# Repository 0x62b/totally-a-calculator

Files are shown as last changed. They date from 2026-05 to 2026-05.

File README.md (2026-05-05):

# totally a calculator
This is a RPi Pico powered...calculator...with an extensive library of..."extra apps" one could say.
The sole purpose of this project is to satisfy the ask of one of my classmates :sob:

[Onshape link](https://cad.onshape.com/documents/416f156d5c7fec03dfea0d3a/w/a37f3b67ee07a3cc1823a5f4/e/b4b6719643a130719caaa4b0)
Note: the display appears to be unaligned due to the fact that i used a different display to the model in the render. However, I designed the case around the display being used, so it should be fine.

## Repo structure
`firmware/` for the (not completed) firmware
`cad/` for CAD design files
`images/` for images in this readme
`pcb/` for KiCad design files and `pcb/gerbers` for production files
`bom.csv` for BOM

## Cost
The BOM prices are approximate due to conversion rates and Aliexpress fluctuations
BOM: 27.03 USD
PCB: 4 USD + 1.5 USD shipping (approx)
Total: 32.53 USD

## Assembly
Prerequisites: print the case parts and solder the PCB
1. Put PCB into bottom case
2. Screw top case onto bottom case
3. Glue or otherwise stick each individual keycap onto the buttons
4. Attach the OLED
5. Screw it in
6. Flash the MicroPython firmware for the Pico
7. Upload the python file in `firmware/`
8. yay

## Images

### Schematic
Beautifully clean and organised (/s) schematic
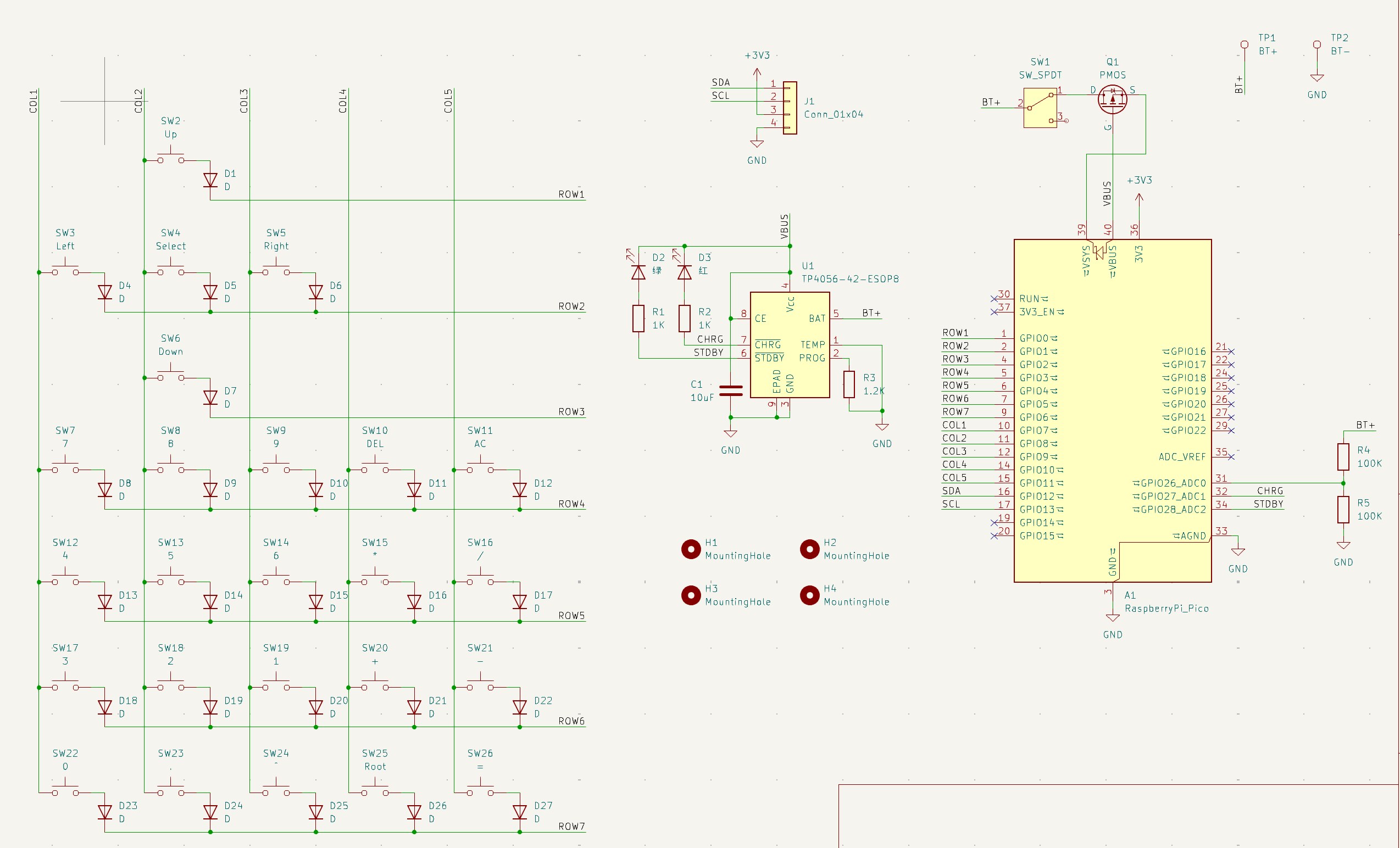
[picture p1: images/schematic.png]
schematic


### PCB render
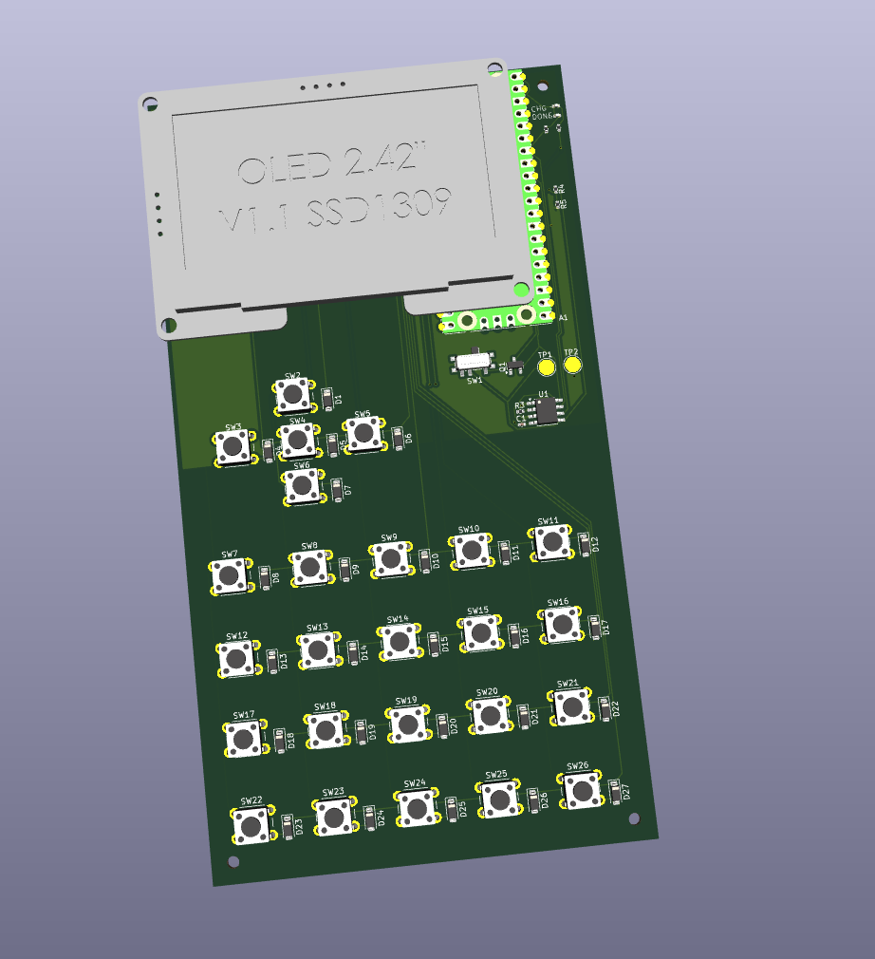
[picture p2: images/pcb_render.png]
pcb render


### Full render
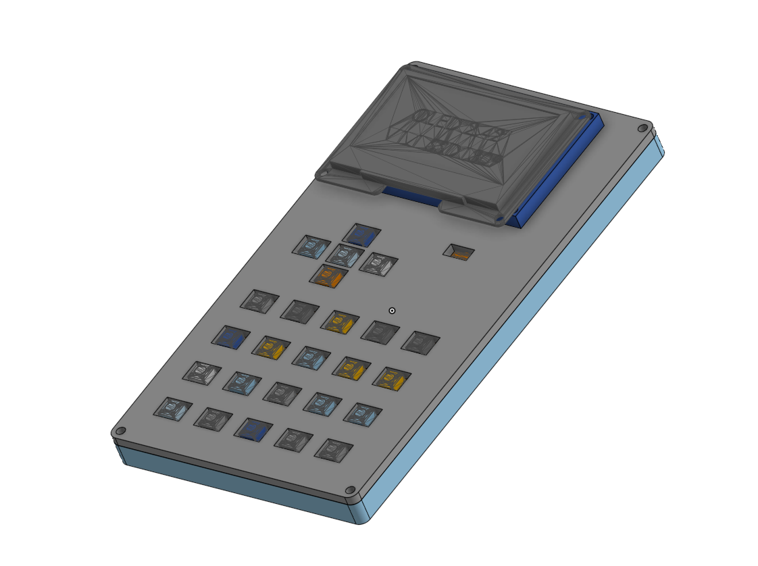
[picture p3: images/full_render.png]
full render


### Zine
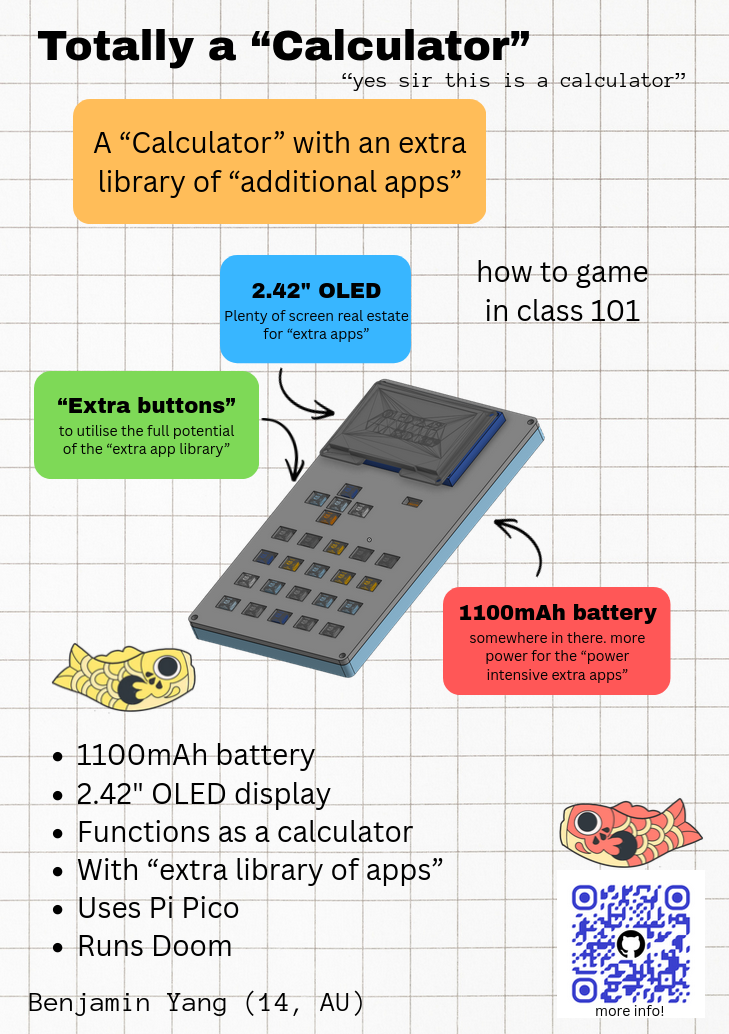
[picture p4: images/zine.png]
zine


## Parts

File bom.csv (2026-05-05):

Item | Unit Price(AUD) | Quantity | Extended Price(AUD) | Extended Price(USD) | Notes | Link
OLED | 18.49 | 1 | 18.49 | 13.22 | N/A | https://www.aliexpress.com/item/1005009013981317.html
Buttons | 3.79 | 1 | 3.79 | 2.71 | 50 in pack | https://www.aliexpress.com/item/1005001813038293.html
Green LED | 0 | 1 | 0 | 0 | owned | N/A
Red LED | 0 | 1 | 0 | 0 | owned | N/A
1K resistor | 0 | 2 | 0 | 0 | owned | N/A
100K resistor | 0 | 2 | 0 | 0 | owned | N/A
1.2K resistor | 2.48 | 1 | 2.48 | 1.77 | 300 per pack | https://www.aliexpress.com/item/1005011779163101.html
TP4056 | 4.01 | 1 | 4.01 | 2.87 | 10 per pack - TC4056A | https://www.aliexpress.com/item/1005010183126676.html
1100mAh battery | 0 | 1 | 0 | 0 | owned | https://core-electronics.com.au/polymer-lithium-ion-battery-1000mah-38458.html
SPDT switch | 2.89 | 1 | 2.89 | 2.07 | 50 per pack | https://www.aliexpress.com/item/4000685483225.html
DMG2305UX P-MOSFET | 6.14 | 1 | 6.14 | 4.39 | 30 per pack | https://www.aliexpress.com/item/1005007188534627.html
Pi Pico | 0 | 1 | 0 | 0 | owned | https://core-electronics.com.au/raspberry-pi-pico-2-w-wireless.html
M3 screws | 0 | 8 | 0 | 0 | owned | N/A

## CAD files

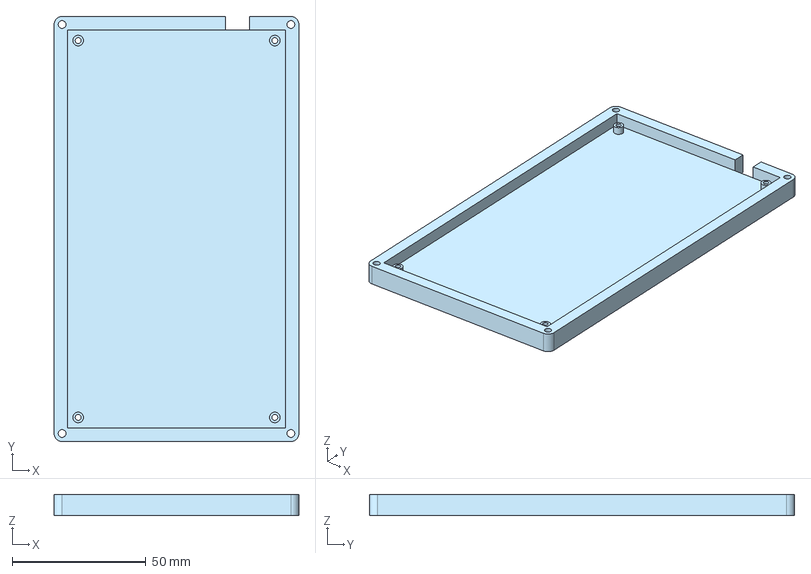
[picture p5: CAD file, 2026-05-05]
cad/bottom case.step
91.6 x 159.0 x 8.00 mm

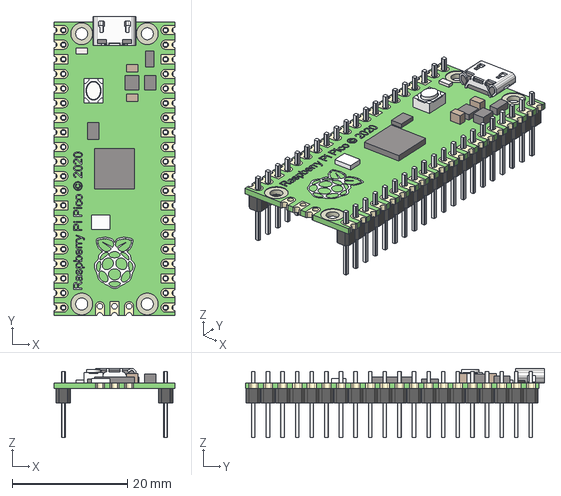
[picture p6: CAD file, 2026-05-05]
pcb/raspberry pi pico with contacts.step
21.0 x 52.0 x 12.0 mm
ножка x 20
ножка v3(Mirror) x 20

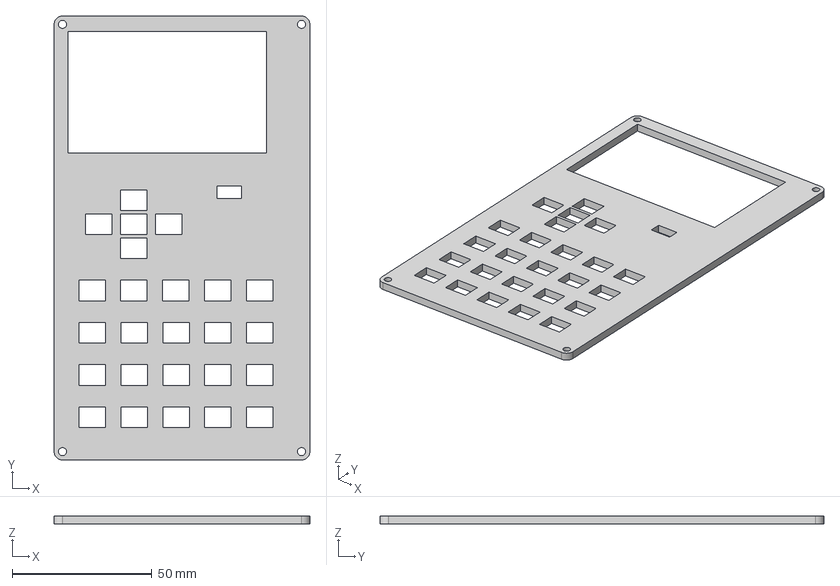
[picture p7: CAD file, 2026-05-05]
cad/top case.step
91.6 x 159.0 x 3.00 mm

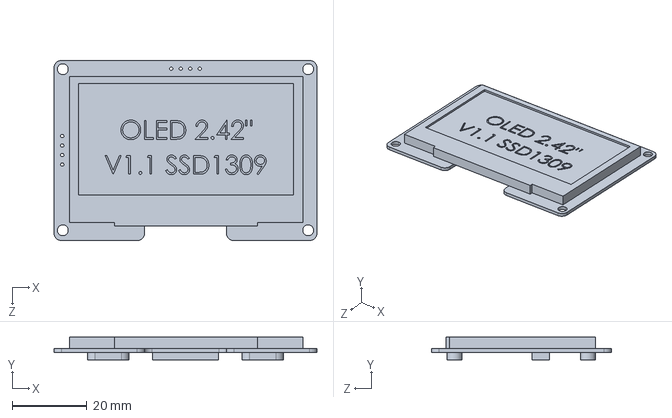
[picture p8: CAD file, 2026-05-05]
pcb/OLED 2.42 V1.1 SSD1309.STEP
70.2 x 6.10 x 48.1 mm

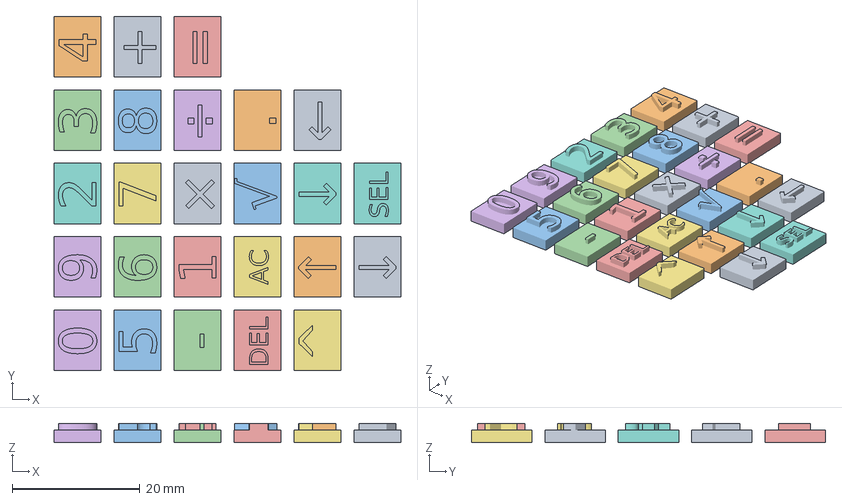
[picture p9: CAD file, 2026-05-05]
cad/keys.3mf
54.4 x 55.5 x 2.98 mm

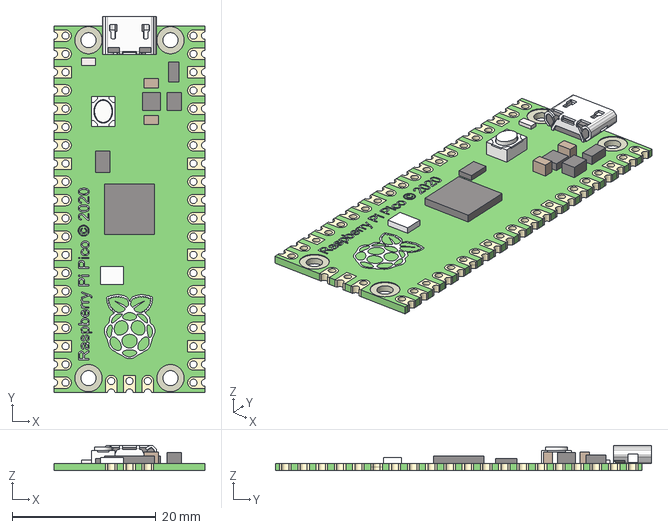
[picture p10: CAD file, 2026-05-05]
pcb/raspberry pi pico.step
21.0 x 52.3 x 3.50 mm

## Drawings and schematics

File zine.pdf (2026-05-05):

## Totally a “Calculator”

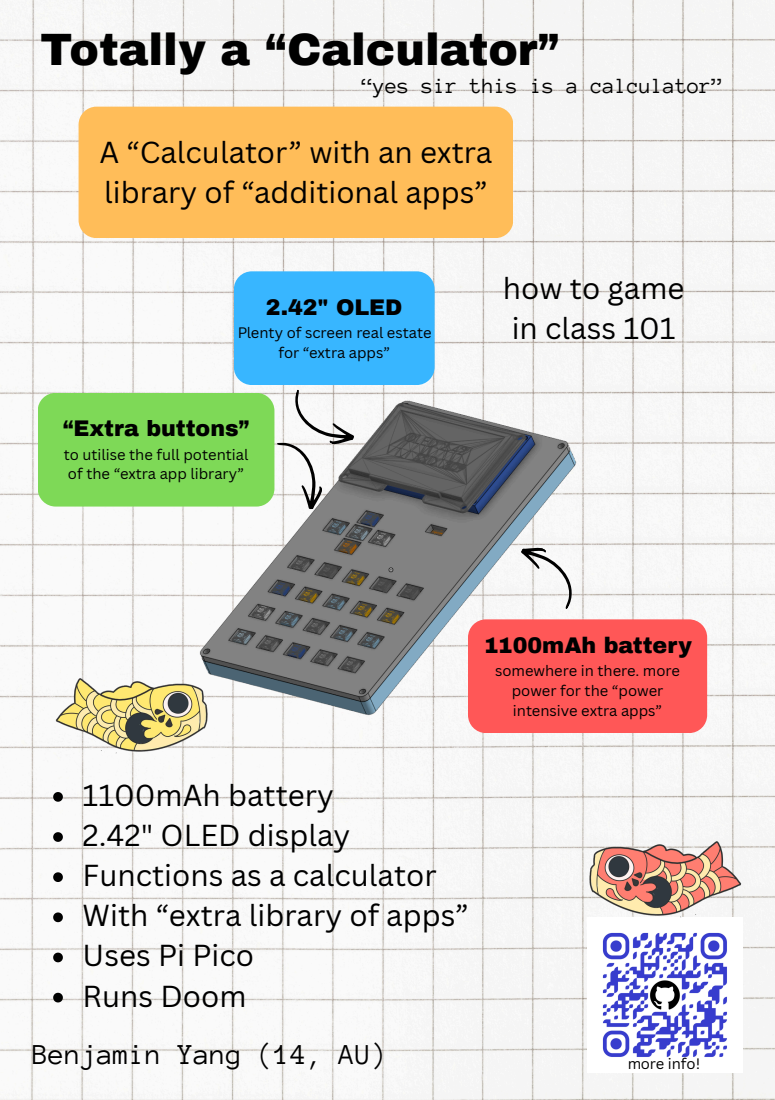
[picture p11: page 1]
more info!

“yes sir this is a calculator”

A “Calculator” with an extra
library of “additional apps”

how to game
in class 101

2.42" OLED
Plenty of screen real estate
for “extra apps”

“Extra buttons”
to utilise the full potential
of the “extra app library”

1100mAh battery
somewhere in there. more
power for the “power
intensive extra apps”

2.42" OLED display
Functions as a calculator
With “extra library of apps”
Uses Pi Pico
Runs Doom

Benjamin Yang (14, AU)

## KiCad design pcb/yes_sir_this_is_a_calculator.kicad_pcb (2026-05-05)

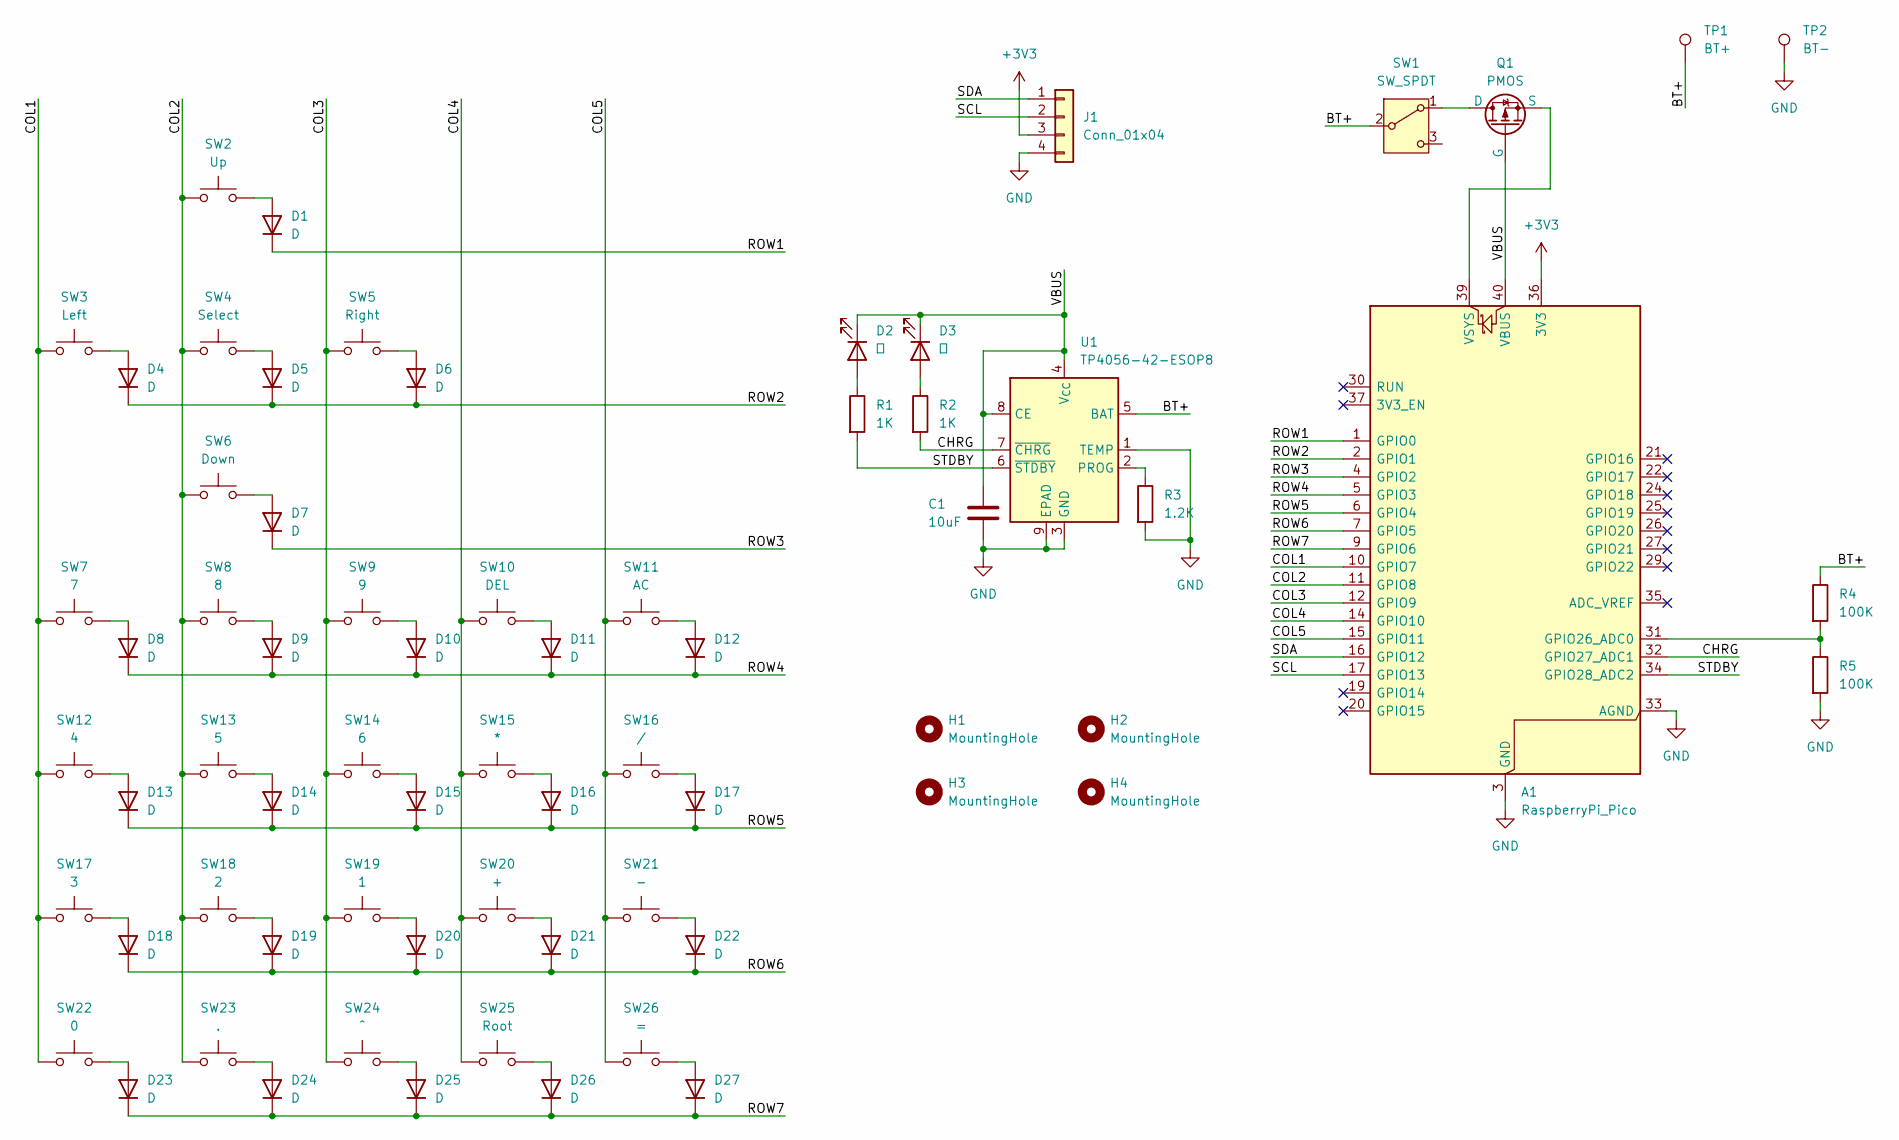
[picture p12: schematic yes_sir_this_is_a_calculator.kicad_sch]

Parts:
A1: RaspberryPi_Pico; RaspberryPi_Pico_Common_Unspecified
C1: 10uF; C_0402_1005Metric
D1, D4, D5, D6, D7, D8, D9, D10, D11, D12, D13, D14, D15, D16, D17, D18, D19, D20, D21, D22, D23, D24, D25, D26, D27: D; D_SOD-123
D2: 绿; LED_0402_1005Metric
D3: 红; LED_0402_1005Metric
H1, H2, H3, H4: MountingHole; MountingHole_2.2mm_M2
J1: Conn_01x04; PinSocket_1x04_P2.54mm_Vertical
Q1: PMOS; SOT-23
R1, R2: 1K; R_0402_1005Metric
R3: 1.2K; R_0402_1005Metric
R4, R5: 100K; R_0402_1005Metric
SW1: SW_SPDT; SW_SPDT_PCM12
SW2: Up; SW_PUSH_6mm
SW3: Left; SW_PUSH_6mm
SW4: Select; SW_PUSH_6mm
SW5: Right; SW_PUSH_6mm
SW6: Down; SW_PUSH_6mm
SW7: 7; SW_PUSH_6mm
SW8: 8; SW_PUSH_6mm
SW9: 9; SW_PUSH_6mm
SW10: DEL; SW_PUSH_6mm
SW11: AC; SW_PUSH_6mm
SW12: 4; SW_PUSH_6mm
SW13: 5; SW_PUSH_6mm
SW14: 6; SW_PUSH_6mm
SW15: *; SW_PUSH_6mm
SW16: /; SW_PUSH_6mm
SW17: 3; SW_PUSH_6mm
SW18: 2; SW_PUSH_6mm
SW19: 1; SW_PUSH_6mm
SW20: +; SW_PUSH_6mm
SW21: -; SW_PUSH_6mm
SW22: 0; SW_PUSH_6mm
SW23: .; SW_PUSH_6mm
SW24: ^; SW_PUSH_6mm
SW25: Root; SW_PUSH_6mm
SW26: =; SW_PUSH_6mm
TP1: BT+; TestPoint_Pad_D3.0mm
TP2: BT-; TestPoint_Pad_D3.0mm
U1: TP4056-42-ESOP8; SOIC-8-1EP_3.9x4.9mm_P1.27mm_EP2.41x3.3mm_ThermalVias

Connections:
+3V3: A1.36 (3V3), J1.3
/BT+: R4.1, SW1.2 (B), TP1.1, U1.5 (BAT)
/CHRG: A1.32 (GPIO27_ADC1), R2.2, U1.7 (~CHRG)
/COL1: A1.10 (GPIO7), SW3.1, SW7.1, SW12.1, SW17.1, SW22.1
/COL2: A1.11 (GPIO8), SW2.1, SW4.1, SW6.1, SW8.1, SW13.1, SW18.1, SW23.1
/COL3: A1.12 (GPIO9), SW5.1, SW9.1, SW14.1, SW19.1, SW24.1
/COL4: A1.14 (GPIO10), SW10.1, SW15.1, SW20.1, SW25.1
/COL5: A1.15 (GPIO11), SW11.1, SW16.1, SW21.1, SW26.1
/ROW1: A1.1 (GPIO0), D1.1 (K)
/ROW2: A1.2 (GPIO1), D4.1 (K), D5.1 (K), D6.1 (K)
/ROW3: A1.4 (GPIO2), D7.1 (K)
/ROW4: A1.5 (GPIO3), D8.1 (K), D9.1 (K), D10.1 (K), D11.1 (K), D12.1 (K)
/ROW5: A1.6 (GPIO4), D13.1 (K), D14.1 (K), D15.1 (K), D16.1 (K), D17.1 (K)
/ROW6: A1.7 (GPIO5), D18.1 (K), D19.1 (K), D20.1 (K), D21.1 (K), D22.1 (K)
/ROW7: A1.9 (GPIO6), D23.1 (K), D24.1 (K), D25.1 (K), D26.1 (K), D27.1 (K)
/SCL: A1.17 (GPIO13), J1.2
/SDA: A1.16 (GPIO12), J1.1
/STDBY: A1.34 (GPIO28_ADC2), R1.2, U1.6 (~STDBY)
/VBUS: A1.40 (VBUS), C1.2, D2.1 (K), D3.1 (K), Q1.2 (G), U1.4 (V_{CC}), U1.8 (CE)
GND: A1.3 (GND), A1.8 (GND), A1.13 (GND), A1.18 (GND), A1.23 (GND), A1.28 (GND), A1.33 (AGND), A1.38 (GND), C1.1, J1.4, R3.2, R5.2, TP2.1, U1.1 (TEMP), U1.3 (GND), U1.9 (EPAD)
unnamed: A1.31 (GPIO26_ADC0), R4.2, R5.1
unnamed: A1.39 (VSYS), Q1.3 (S)
unnamed: D1.2 (A), SW2.2
unnamed: D2.2 (A), R1.1
unnamed: D3.2 (A), R2.1
unnamed: D4.2 (A), SW3.2
unnamed: D5.2 (A), SW4.2
unnamed: D6.2 (A), SW5.2
unnamed: D7.2 (A), SW6.2
unnamed: D8.2 (A), SW7.2
unnamed: D9.2 (A), SW8.2
unnamed: D10.2 (A), SW9.2
unnamed: D11.2 (A), SW10.2
unnamed: D12.2 (A), SW11.2
unnamed: D13.2 (A), SW12.2
unnamed: D14.2 (A), SW13.2
unnamed: D15.2 (A), SW14.2
unnamed: D16.2 (A), SW15.2
unnamed: D17.2 (A), SW16.2
unnamed: D18.2 (A), SW17.2
unnamed: D19.2 (A), SW18.2
unnamed: D20.2 (A), SW19.2
unnamed: D21.2 (A), SW20.2
unnamed: D22.2 (A), SW21.2
unnamed: D23.2 (A), SW22.2
unnamed: D24.2 (A), SW23.2
unnamed: D25.2 (A), SW24.2
unnamed: D26.2 (A), SW25.2
unnamed: D27.2 (A), SW26.2
unnamed: Q1.1 (D), SW1.1 (A)
unnamed: R3.1, U1.2 (PROG)

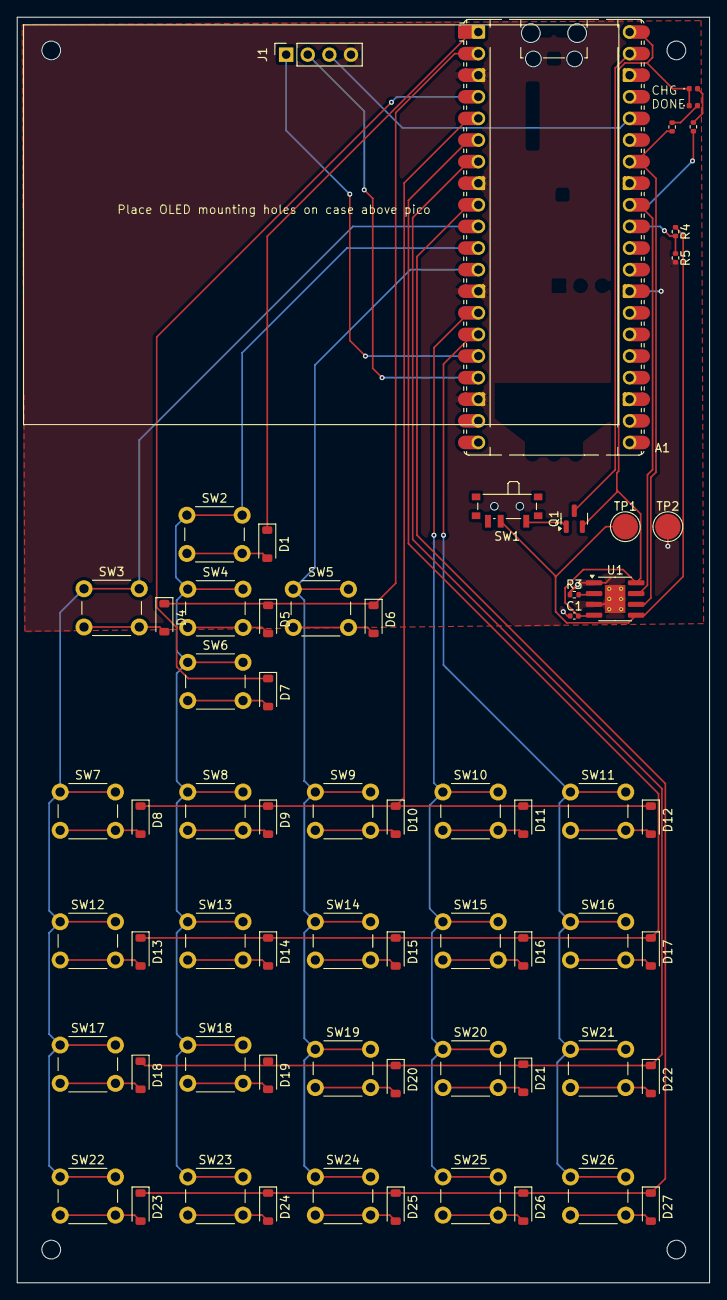
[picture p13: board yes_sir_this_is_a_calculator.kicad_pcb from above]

Board: 2 copper layers, 81.4 x 148.8 mm, 69 parts (0 on the bottom side), 51 nets.

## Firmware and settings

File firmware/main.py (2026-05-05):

from machine import Pin
import time

ROW_PINS = [0, 1, 2, 3, 4, 5, 6]
COL_PINS = [7, 8, 9, 10, 11]
SDA_PIN = 12
SCL_PIN = 13

rows = [Pin(p, Pin.OUT) for p in ROW_PINS]
cols = [Pin(p, Pin.IN, Pin.PULL_UP) for p in COL_PINS]

for r in rows:
  r.value(1)

keymap = [
  ["",     "Up",   "",      "",    ""],
  ["Left", "Sel",  "Right", "",    ""],
  ["",     "Down", "",      "",    ""],
  ["7",    "8",    "9",     "DEL", "AC"],
  ["4",    "5",    "6",     "*",   "/"],
  ["3",    "2",    "1",     "+",   "-"],
  ["0",    ".",    "~",     "SQT", "="]
]

def scan():
  for r in rows:
    r.value(0)
    
    for c in cols:
      if c.value() == 0:
        r.value(1)
        return keymap[rows.index(r)][cols.index(c)]
        
    r.value(1)

while True:
  key = scan()
  if key:
    print(key)
  
  time.sleep(0.05)

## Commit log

2026-05-05 CAD files
    [bottom case.step, top case.step]
2026-05-05 add pico to bom
    [bom.csv]
2026-05-28 add gerbers
    [yes_sir_this_is_a_calculator-B_Cu.gbr, yes_sir_this_is_a_calculator-B_Mask.gbr, yes_sir_this_is_a_calculator-B_Paste.gbr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]
